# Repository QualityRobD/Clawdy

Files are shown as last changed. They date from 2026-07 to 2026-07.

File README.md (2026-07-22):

# Clawdy: The Anthropic Status Monitor

Clawdy is a dedicated desktop hardware monitor that tracks the operational status of Claude's infrastructure (claude.ai, Console, API, and Code). Using two I2C OLED displays as expressive "eyes," the system provides immediate, ambient visual feedback on service degradation, API outages, and network connectivity.

## Features
* **Real-Time API Polling:** Tracks `status.claude.com` for active outages and reflects the system health natively.
* **Expressive State Machine:** Features over a dozen eye animations (winks, lazy eyes, matrix rain) during normal operation, and distinct visual alert states (Angry Eyes, X Eyes) when infrastructure degrades or a schema mismatch occurs.
* **Resilient Polling:** Built with a reliability-first mindset, gracefully handling network timeouts, HTTP errors, and JSON payload changes without hard-crashing. 
* **Dynamic WiFi Provisioning:** Uses `WiFiManager` to spin up a captive portal (`Clawdy_Setup`) on first boot, keeping local network credentials entirely out of the source code.
* **Hardware Factory Reset:** Built-in startup trap allows for easy network clearing.

## 📶 Wi-Fi Setup & User Manual

Clawdy handles network credentials securely by keeping them off the codebase and storing them directly in local memory.
* The XIAO ESP32-C5 microcontroller supports dual-band Wi-Fi 6 (2.4 GHz and 5 GHz), allowing Clawdy to connect to most modern networks without compatibility issues.
* The Wi-Fi manager allows access to standard networks where a name and password are required. (Enterprise networks requiring a username/VPN are not currently supported).

### Initial Setup (First Boot)
1. **Power On:** Plug Clawdy in. You will see the "CLAWDY" splash screen for 3 seconds.
2. **Access Point Mode:** Because no networks are saved, the screens will read `"CONNECTING TO: WIFI"`. Clawdy will broadcast its own temporary Wi-Fi network.
3. **Connect:** Use your phone or computer to connect to the Wi-Fi network named **`Clawdy_Setup`**.
4. **Configure:** A captive portal should automatically pop up. (If it doesn't, open a web browser and navigate to `192.168.4.1`). Click "Configure WiFi", select your local network, and enter your password.
5. **Success:** Clawdy will save the credentials to its flash memory, automatically restart, and perform a "Happy" eye trick once connected to the internet.

### Setup Timeout 
For security and stability, the configuration portal will only stay active for **3 minutes (180 seconds)**. 
* If you do not enter credentials within that window, Clawdy will display `"SETUP TIMEOUT / REBOOTING..."` and restart itself to try again.

### How to Reset / Wipe Wi-Fi Credentials
If you move Clawdy to a new location or change your router password, you'll need to wipe the old network from memory:
1. Power cycle (unplug and replug) the device.
2. Immediately after the "CLAWDY" splash screen finishes, a 3-second trap window will appear reading `"HOLD 'BOOT' TO WIPE WIFI"`.
3. Press and hold your BOOT button (wired to GPIO 28) during this window.
4. The screens will switch to `"WIPING..."`. 
5. The device will completely erase the old credentials and reboot back into the initial `Clawdy_Setup` Access Point mode so you can connect it to the new network.

## Bill of Materials (BOM)

**Electronics & Circuitry**
* 1x Seeed Studio XIAO ESP32-C5 development board with soldered pins
* 2x 0.96 Inch OLED Display Module 128x64 SSD1306 (I2C)
* 1x Breadboard
* 24 AWG solid core hook wire kit (6 colors)
* 1x Power Battery
* 1x Carry case

**Soldering Equipment**
* Pinecil soldering iron
* 65W Anker Nano USB-C power adapter and high-power USB-C cable
* AUSTOR 60-40 Tin Lead Rosin Core Solder Wire
* Desoldering wick and soldering flux paste
* Soldering desk pad

**3D Printing & Enclosure**
* Terracotta Matte PLA filament

**Post-Processing & Finishing**
* Wet sandpaper (180, 300, 600, 1000, 1500, and 2000 grit)
* Micro-Mesh SoftTouch Pads (1500- 12000)
* Tamiya Polishing Compount Fine
* Tamiya Polishing Compount Finish
* Renaissance Micro-Crystalline Wax Polish (uncessary, but adds extra sheen and protection)
* High-quality microfiber towels
* High-quality wood polishing microfiber buffing pads

## 3D Printed Enclosure
* The repository includes a large edition Claw-D mascot chassis featuring a direct rear USB-C cable pass-through.
* The chassis features a precision screen retention slot designed to fit standard 0.96-inch PCBs.
* The base of the design utilizes a stable eight leg squid structure.
* The chassis OpenSCAD file supports multiple isolated print modes, allowing you to independently print the base, cap, legs, and arms.
* The independent arms mode automatically generates the pieces laid flat for vertical pin printing.
* The repository includes a separate internal electronics sled.
* The sled features specific left and right OLED pockets to securely seat the displays.
* The sled incorporates an ESP32 cradle base with dedicated underside clearance for USB ports and buttons.
* The sled utilizes 0.5mm friction tolerance rails on the outside to easily adjust the fit.
  * *Note on tolerances:* The 0.5mm friction rails and 0.4mm global clearances were designed and tested on a Bambu Lab P2S. If you are using an older or less precise printer, you may need to apply slight negative horizontal expansion in your slicer.

## Software Dependencies
* [Adafruit GFX Library](https://github.com/adafruit/Adafruit-GFX-Library)
* [Adafruit SSD1306](https://github.com/adafruit/Adafruit_SSD1306)
* [WiFiManager](https://github.com/tzapu/WiFiManager)
* **ArduinoJson (IMPORTANT: Must use Version 6.x)** 
  *(Note: This codebase utilizes `DynamicJsonDocument`, which was deprecated in ArduinoJson v7).*

## Architecture Notes
* `program_sketch.ino`: The main operational loop and rendering pipeline.
* `anthropic_status.h`: The networking thread, managing HTTP/TLS connections and JSON payload deserialization.
* `eye_tricks.h`: The geometry and animation library for the OLED eyes.

## License
MIT License

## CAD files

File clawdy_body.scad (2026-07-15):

// =========================================================================
// CLAW-D MASCOT: LARGE EDITION (SLED READY, REAR SCREW MOUNTS)
// =========================================================================

/* [Fixed Hardware Specifications] */
pcb_w = 27.3;         // Physical width of standard 0.96" PCB
glass_t = 2.4;        // Front of glass to back of PCB
clearance = 0.4;      // 3D printing tolerance fit
$fn = 24;             // Curve smoothness

/* [Adjustable Features] */
print_mode = "arms";  // [ "assembled", "base", "cap", "legs", "arms" ]
eye_w = 25;           // Width of the front eye cutouts - original: 23
eye_h = 12;           // Height of the front eye cutouts - original: 14
eye_mm_height_adjust = 5;
eye_chamfer = 2.0;    // How much the outer edges slant outward for better viewing angle
top_softness = 1.0;   // How much the outer top edge is chamfered (leaves the rest flat for supports)

usb_hole_height_adjuster = 5.0;

// Variables to protect the internal cavity while adding pin holes
bottom_thickness_added = 2.4; 
pin_height = 3.0;
hole_depth = 3.6; 

clawd_chassis();

module clawd_chassis() {
    
    // 1. HARDCODED LARGE PARAMETERS
    unit = 7.2;
    head_w = 86.4;    // 12 * 7.2
    head_h = 69.12;   // 86.4 / 1.25
    head_d = 39.6;    // 5.5 * 7.2

    if (print_mode == "base" || print_mode == "cap" || print_mode == "assembled") {
        difference() {
            // 2. THE ACCURATE PROPORTIONAL OUTER SHELL
            union() {
                // Main Head (Bottom extended downward by bottom_thickness_added)
                translate([-head_w/2, -head_d/2, 2*unit - bottom_thickness_added]) 
                    cube([head_w, head_d, head_h + bottom_thickness_added]);
                
                if (print_mode == "assembled") {
                    // Left Side Stub/Arm
                    translate([-head_w/2 - 2*unit, -unit/2, head_h/2 + unit]) 
                        cube([2*unit, unit, 2*unit]);
                    
                    // Right Side Stub/Arm
                    translate([head_w/2, -unit/2, head_h/2 + unit]) 
                        cube([2*unit, unit, 2*unit]);
                        
                    // ---- STABLE EIGHT LEG SQUID STRUCTURE ----
                    for(x = [-4.5*unit, -2.5*unit, 1.5*unit, 3.5*unit]) {
                        for(y = [-head_d/2, head_d/2 - unit]) {
                            // Legs end where the newly lowered chassis begins
                            translate([x, y, 0]) cube([unit, unit, 2*unit - bottom_thickness_added]);
                        }
                    }
                }
            }
            
            // 3. INTERNAL CAVITY (Untouched coordinates)
            translate([-4.5*unit, -head_d/2 + 2.5, 2*unit + 2])
                cube([9*unit, head_d - 5, head_h - 3.8]);
                
            // 4. FRONT FACE EYE WINDOWS (Two-Stage Cut for Supports + Soft Edge)
            translate([-2.5*unit - eye_w/2.75, -head_d/2 - 0.1, head_h - 2.25*unit - eye_h/2 + eye_mm_height_adjust])
                chamfered_eye(is_left = true);
                
            translate([2.5*unit - eye_w/1.5, -head_d/2 - 0.1, head_h - 2.25*unit - eye_h/2 + eye_mm_height_adjust])
                chamfered_eye(is_left = false);
                
            // 5. PRECISION SCREEN RETENTION SLOT (Untouched coordinates)
            translate([-4.5*unit, -head_d/2 + 2.5, 2*unit + 2])
                cube([9*unit, glass_t + clearance, head_h - 3.8]);

            // 6. UPPER WIRING & PIN RELIEF CHANNEL (Untouched coordinates)
            translate([-4.5*unit, -head_d/2 + 2.5, head_h + unit - 2])
                cube([9*unit, head_d - 5, 3]);
                
            // 7. DIRECT REAR USB-C CABLE PASS-THROUGH (Untouched coordinates)
            translate([-8, head_d/2 - 4, 2*unit + usb_hole_height_adjuster])
                cube([16, 10, 10]);

            // 8. LEG ALIGNMENT HOLES
            if (print_mode == "base") {
                for(x = [-4.5*unit, -2.5*unit, 1.5*unit, 3.5*unit]) {
                    for(y = [-head_d/2, head_d/2 - unit]) {
                        // Cut upwards from the newly lowered chassis bottom
                        translate([x + 1.2 - clearance/2, y + 1.2 - clearance/2, 2*unit - bottom_thickness_added - 0.1])
                            cube([unit - 2.4 + clearance, unit - 2.4 + clearance, hole_depth + 0.1]);
                    }
                }
            }
            
            // 8.5 ARM ALIGNMENT HOLES
            if (print_mode == "base") {
                // Left Arm Hole
                translate([-head_w/2 - 0.1, -unit/2 + 1.2 - clearance/2, head_h/2 + unit + 1.2 - clearance/2])
                    cube([hole_depth + 0.1, unit - 2.4 + clearance, 2*unit - 2.4 + clearance]);
                    
                // Right Arm Hole
                translate([head_w/2 - hole_depth, -unit/2 + 1.2 - clearance/2, head_h/2 + unit + 1.2 - clearance/2])
                    cube([hole_depth + 0.1, unit - 2.4 + clearance, 2*unit - 2.4 + clearance]);
            }
                
            // 9. TUPPERWARE SPLIT CUTTERS
            if (print_mode == "base") {
                difference() {
                    translate([-head_w/2 - 5, -head_d/2 - 5, 2*unit + head_h - 4]) 
                        cube([head_w + 10, head_d + 10, 20]);
                    translate([-head_w/2 + 2, -head_d/2 + 2, 2*unit + head_h - 4]) 
                        cube([head_w - 4, head_d - 4, 2]);
                }
            }
            
            if (print_mode == "cap") {
                translate([-100, -100, -20]) 
                    cube([200, 200, 2*unit + head_h - 4 + 20]);
                    
                translate([-head_w/2 + 1.8, -head_d/2 + 1.8, 2*unit + head_h - 4 - 0.1]) 
                    cube([head_w - 3.6, head_d - 3.6, 2.2]);
            }
        }
    }

    // 10. INDEPENDENT LEGS MODE
    if (print_mode == "legs") {
        for(x = [-4.5*unit, -2.5*unit, 1.5*unit, 3.5*unit]) {
            for(y = [-head_d/2, head_d/2 - unit]) {
                union() {
                    // Leg base (exactly meets the lowered bottom of the chassis)
                    translate([x, y, 0]) 
                        cube([unit, unit, 2*unit - bottom_thickness_added]);
                    // Alignment pin
                    translate([x + 1.2, y + 1.2, 2*unit - bottom_thickness_added]) 
                        cube([unit - 2.4, unit - 2.4, pin_height]);
                }
            }
        }
    }
    
    // 11. INDEPENDENT ARMS MODE (Laid flat for vertical pin printing)
    if (print_mode == "arms") {
        // Generates two identical arms side-by-side on the Z=0 plane
        for(x = [-1.5*unit, 1.5*unit]) {
            translate([x - unit, -unit/2, 0]) {
                union() {
                    // Arm body (laying on its flat side)
                    cube([2*unit, unit, 2*unit]);
                    // Alignment pin (pointing straight up)
                    translate([1.2, 1.2, 2*unit]) 
                        cube([2*unit - 2.4, unit - 2.4, pin_height]);
                }
            }
        }
    }
}
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

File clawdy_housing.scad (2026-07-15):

// ==========================================
// CLAW-D MASCOT: INTERNAL ELECTRONICS SLED
// ==========================================

oled_w = 27.8; // old: 27.8
oled_h = 28.6; // old: 28.0 & 28.02

esp_l = 26.5; // esp cradel wall length
esp_w = 17.85; // esp cradel wall space distance (old: 18mm)
esp_h = 12.0; // esp cradel wall height
esp_z_lift = 6.0; // Raises the board to create component clearance underneath
esp_y_offset = 0; // Negative = closer to the front wall, Positive = further back

sled_width = 63.0;  

// --- ASYMMETRICAL ADJUSTMENT ---
// Front restored to original position (-16.5)
// Back extended by exactly 1mm from original (16.5 -> 17.5)
front_y = -16.5; 
back_y = 17.5;   
sled_depth = back_y - front_y; // Dynamically calculates to 34.0mm

sled_height = 65.0; 
wall_thick = 2.0;
front_wall_thick = 4.0; // RESTORED to 4.0 for OLED clearance
eye_z_offset = 25.12; // eyehole vertical position

render_sled();

module render_sled() {
    difference() {
        union() {
            // Main U-Shape Sled
            difference() {
                translate([-sled_width/2, front_y, 0])
                    cube([sled_width, sled_depth, sled_height]);
                
                translate([-(sled_width - wall_thick*2)/2, front_y + front_wall_thick, wall_thick])
                    cube([sled_width - wall_thick*2, sled_depth, sled_height]);
            }
            
            // ESP32 Cradle Base (Extended to front wall, raised by 2mm)
            translate([-(esp_w + 2)/2, front_y + front_wall_thick, wall_thick])
                cube([esp_w + 2, back_y - (front_y + front_wall_thick), esp_h + esp_z_lift]);

            // ESP32 Cradle shelf (Raised by 2mm)
            translate([-(esp_w + 2)/2, front_y + front_wall_thick, wall_thick + 12 + esp_z_lift])
                cube([esp_w + 2, ((back_y - esp_l + esp_y_offset) - (front_y + front_wall_thick)) + 14.5, 2]);
                
    
            // 0.5mm Friction Tolerance Rails (outside of sled to easily adjust length)
            translate([-sled_width/2 - 0.7, front_y, 0])
                cube([0.7, sled_depth, sled_height]);
            translate([sled_width/2, front_y, 0])
                cube([0.7, sled_depth, sled_height]);
        }
        
        // --- SUBTRACTIONS ---
        
        // ESP32 Drop-In Seat 
        // Lifted by esp_z_lift so the board rests on a 2mm ledge
        translate([-esp_w/2, back_y - esp_l + esp_y_offset, wall_thick + esp_z_lift + 0.1])
            cube([esp_w, esp_l + 1, esp_h]);

        // ESP32 Underside Component Clearance (USB & Buttons)
        // 10mm wide gap leaves ~3.9mm ledges on both sides for the board to sit on.
        depth = back_y - 16 + esp_y_offset;
        translate([-10/2, depth, 3])
            cube([10, 16.1, esp_z_lift + 0.2]);

        // Left OLED Pocket
        translate([-sled_width/2 + wall_thick + 0.5, front_y - 0.1, eye_z_offset])
            cube([oled_w, front_wall_thick + 1, oled_h]);
            
        // Right OLED Pocket
        translate([sled_width/2 - wall_thick - 0.5 - oled_w, front_y - 0.1, eye_z_offset])
            cube([oled_w, front_wall_thick + 1, oled_h]);
    }
}

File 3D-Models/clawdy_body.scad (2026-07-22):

// =========================================================================
// CLAW-D MASCOT: LARGE EDITION (SLED READY, REAR SCREW MOUNTS)
// =========================================================================

/* [Fixed Hardware Specifications] */
pcb_w     = 27.3;             // Physical width of standard 0.96" OLED PCB
glass_t   = 2.4;              // Depth from front of OLED glass to back of PCB
clearance = 0.4;              // Global 3D printing tolerance fit
$fn       = 24;               // Curve smoothness (resolution for cylinders/arcs)

/* [Adjustable Features] */
print_mode           = "base"; // [ "assembled", "base", "cap", "legs", "arms" ]
eye_w                = 25;     // Width of the front eye cutouts (original: 23)
eye_h                = 12;     // Height of the front eye cutouts (original: 14)
eye_mm_height_adjust = 5;      // Vertical shift for the eye cutouts
eye_chamfer          = 2.0;    // Outward slant on outer edges for better viewing angle
top_softness         = 1.0;    // Top edge chamfer amount (leaves the rest flat for supports)
leg_inset            = 3.0;    // Inward adjustment distance for front and back legs

usb_hole_height_adjuster = 5.0; // Vertical shift for the rear USB-C cable pass-through

// Variables to protect the internal cavity while adding alignment pin holes
bottom_thickness_added = 2.4;  // Extra thickness added to the base for structural integrity
pin_height             = 3.0;  // Height of the alignment pins (arms/legs)
hole_depth             = 3.6;  // Depth of the receiving holes (allows 0.6mm clearance for glue/fit)

/* [Base Pocket Adjustments] */
pocket_w_extra = clearance + 0.2; // Extra width for base pocket (default was global clearance: 0.4)
pocket_d_extra = clearance + 0.2; // Extra depth for base pocket (default was global clearance: 0.4)
pocket_h_extra = clearance + 0.0; // Extra height/depth for base pocket (default was hardcoded 0.1)

/* [Magnetic Clasp & Split] */
magnet_dia      = 5.2; // Diameter of hidden pocket (+0.2mm tolerance for 5mm magnet)
magnet_depth    = 3.2; // Depth of hidden pocket (+0.2mm tolerance for 3mm magnet)
cover_thickness = 0.6; // Layers of plastic hiding the magnet (0.6 = 3x 0.2mm print layers)

/* [Sled Button Alignment] */
button_hole_d              = 2.0;  // Hole size for boot/reset access (sized for a paperclip)
esp_w                      = 18.2; // Matches internal sled's ESP width for exact offset mapping
left_button_hole_x_offset  = 4.25; // X-axis offset for the left (BOOT) button
right_button_hole_x_offset = 5.0;  // X-axis offset for the right (RESET) button
button_hole_y              = -5;   // Y-axis depth alignment (Maps to sled's updated math: 17.5 - 22.25)

// =========================================================================
// MAIN EXECUTION
// =========================================================================

if (print_mode == "cap") {
    // Flips the cap 180 degrees and drops the flat seam exactly to the Z=0 build plate
    // Math: Z-height shift = (2 * unit + head_h - 4)
    translate([0, 0, 2*7.2 + 69.12 - 4]) 
        rotate([180, 0, 0]) 
            clawd_chassis();
} else {
    clawd_chassis();
}

// =========================================================================
// CHASSIS MODULE
// =========================================================================

module clawd_chassis() {
    
    // 1. HARDCODED LARGE PARAMETERS
    unit   = 7.2;
    head_w = 86.4;    // 12 * 7.2 (Total head width)
    head_h = 69.12;   // 86.4 / 1.25 (Total head height proportional to width)
    head_d = 39.6;    // 5.5 * 7.2 (Total head depth)
    
    // Split line and Boss parameters for two-part printing
    split_z = 2*unit + head_h - 4; // Z-height where the cap splits from the base
    boss_w  = 6.0;                 // Width of the alignment bosses
    boss_d  = 12.0;                // Depth of the alignment bosses
    boss_h  = 3.0;                 // Height of the alignment bosses
    boss_x  = 37.8;                // X-axis position (centered precisely in the solid side-walls)

    // Render the main body if we are printing the base, cap, or full assembly
    if (print_mode == "base" || print_mode == "cap" || print_mode == "assembled") {
        difference() {
            // 2. THE ACCURATE PROPORTIONAL OUTER SHELL
            union() {
                // Main Head (Bottom extended downward by bottom_thickness_added)
                translate([-head_w/2, -head_d/2, 2*unit - bottom_thickness_added]) 
                    cube([head_w, head_d, head_h + bottom_thickness_added]);
                    
                // Structural Alignment Bosses (Added to Cap for reassembly)
                if (print_mode == "cap" || print_mode == "assembled") {
                    translate([boss_x - boss_w/2, -boss_d/2, split_z - boss_h])
                        cube([boss_w, boss_d, boss_h]);
                    translate([-boss_x - boss_w/2, -boss_d/2, split_z - boss_h])
                        cube([boss_w, boss_d, boss_h]);
                }
                
                // Attach non-removable limbs for 'assembled' visualization
                if (print_mode == "assembled") {
                    // Left Side Stub/Arm
                    translate([-head_w/2 - 2*unit, -unit/2, head_h/2 + unit]) 
                        cube([2*unit, unit, 2*unit]);
                    
                    // Right Side Stub/Arm
                    translate([head_w/2, -unit/2, head_h/2 + unit]) 
                        cube([2*unit, unit, 2*unit]);
                        
                    // ---- STABLE EIGHT LEG SQUID STRUCTURE ----
                    for(x = [-4.5*unit, -2.5*unit, 1.5*unit, 3.5*unit]) {
                        for(y = [-head_d/2 + leg_inset, head_d/2 - unit - leg_inset]) {
                            // Legs end where the newly lowered chassis begins
                            translate([x, y, 0]) 
                                cube([unit, unit, 2*unit - bottom_thickness_added]);
                        }
                    }
                }
            }
            
            // 3. INTERNAL CAVITY (Untouched coordinates)
            // Hollows out the center for the PCB sled and wiring
            translate([-4.5*unit, -head_d/2 + 2.5, 2*unit + 2])
                cube([9*unit, head_d - 5, head_h - 3.8]);
                
            // 4. FRONT FACE EYE WINDOWS (Two-Stage Cut for Supports + Soft Edge)
            eye_shift_x = 0.4; // Fine-tuning offset to perfectly center the eyes
            
            // Left Eye Cutout
            translate([-2.5*unit - eye_w/2.75 + eye_shift_x, -head_d/2 - 0.1, head_h - 2.25*unit - eye_h/2 + eye_mm_height_adjust])
                chamfered_eye(is_left = true);
                
            // Right Eye Cutout
            translate([2.5*unit - eye_w/1.5 + eye_shift_x, -head_d/2 - 0.1, head_h - 2.25*unit - eye_h/2 + eye_mm_height_adjust])
                chamfered_eye(is_left = false);
                
            // 5. PRECISION SCREEN RETENTION SLOT (Untouched coordinates)
            // Secures the OLED glass directly against the front wall
            translate([-4.5*unit, -head_d/2 + 2.5, 2*unit + 2])
                cube([9*unit, glass_t + clearance, head_h - 3.8]);

            // 6. UPPER WIRING & PIN RELIEF CHANNEL (Untouched coordinates)
            // Provides headroom for dupont wires or headers at the top of the sled
            translate([-4.5*unit, -head_d/2 + 2.5, head_h + unit - 2])
                cube([9*unit, head_d - 5, 3]);
                
            // 7. DIRECT REAR USB-C CABLE PASS-THROUGH (Untouched coordinates)
            translate([-8, head_d/2 - 4, 2*unit + usb_hole_height_adjuster])
                cube([16, 10, 10]);
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

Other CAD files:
3D-Models/clawdy_housing.scad

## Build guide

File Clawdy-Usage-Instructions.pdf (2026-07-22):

# Clawdy: Anthropic Status Monitor

Provisioning & Setup

1. Power: Supply standard USB power.
2. Connect: Join the Clawdy_Setup Wi-Fi from any client.
3. Provision: Pass local Wi-Fi credentials via the captive portal (VPN unsupported)

UI Telemetry

- Blinking Eyes: Systems operational.
- 'X' Eyes: Active outage (degraded service scrolls below).
- Angry Brows: Systemic error (e.g., firewall block, routing timeout).

Hardware Toggles

Ensure the microcontroller is fully pushed back into the device. The two buttons are very small and near the back of the device.

- [R] Pinhole: Reboot device
- [B] Pinhole (Wipe): Tap [R]. At the startup prompt, hold [B] for 2 seconds to wipe network config.
- Do this to change wifi settings if you want to connect Clawdy to a new network

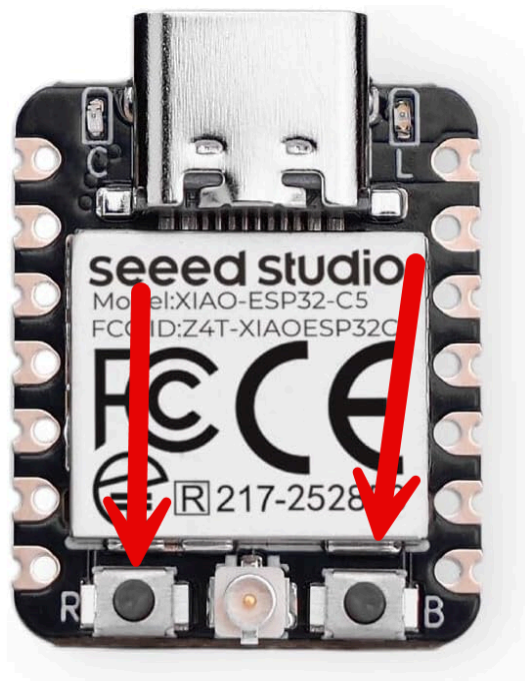
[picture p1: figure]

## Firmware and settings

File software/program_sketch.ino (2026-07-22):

// =========================================================================
// CLAWDY MASCOT: MAIN EXECUTION SCRIPT
// Hardware: ESP32 (Optimized for XIAO ESP32-C5) & Dual 0.96" I2C OLEDs
// =========================================================================

#include <SPI.h>
#include <Wire.h>
#include <Adafruit_GFX.h>
#include <Adafruit_SSD1306.h>
#include <WiFiManager.h>
#include <esp_wifi.h>

// LINK SEPARATE TAB LOGIC: Pulls in the network engine compiled in your other sub-files
// These files inject external variables like 'clawdExpressionState' and 'downTargetText'
#include "anthropic_status.h" 
#include "eye_tricks.h"

// --- OLED HARDWARE DEFINITIONS ---
#define SCREEN_WIDTH         128 
#define SCREEN_HEIGHT        64 
#define OLED_RESET           -1 
#define SCREEN_ADDRESS_LEFT  0x3D // Jumpered/Resistor-modified OLED address
#define SCREEN_ADDRESS_RIGHT 0x3C // Default OLED address

// --- ESP32 CHIP-SPECIFIC BOOT BUTTON PIN MAPPING ---
#if CONFIG_IDF_TARGET_ESP32C5
  #define BOOT_BUTTON 28 // XIAO ESP32-C5 boot pin
#elif CONFIG_IDF_TARGET_ESP32C3 || CONFIG_IDF_TARGET_ESP32C6
  #define BOOT_BUTTON 9  // Standard C3/C6 boot pin
#else
  #define BOOT_BUTTON 0  // Classic ESP32, S2, and S3 boot pin
#endif

// Instantiate the dual display objects sharing the same I2C bus
Adafruit_SSD1306 leftEye(SCREEN_WIDTH, SCREEN_HEIGHT, &Wire, OLED_RESET);
Adafruit_SSD1306 rightEye(SCREEN_WIDTH, SCREEN_HEIGHT, &Wire, OLED_RESET);

// --- GLOBAL STATE VARIABLES ---
// Exposed to sub-tabs via 'extern' in their respective header files
bool clawdOperational    = true; 
bool eyesOpen            = true; 
int  lastExpressionState = 0; // Tracks previous state to detect recovery events

unsigned long nextTandemBlink = 0; 
unsigned long nextStatusCheck = 0;

const int           blinkDuration   = 150;   // Milliseconds the eyes stay closed during a blink
const unsigned long apiPollInterval = 60000; // Frequency of checking the Anthropic status API

// =========================================================================
// SYSTEM INITIALIZATION
// =========================================================================

void setup() {
  delay(500); // Startup rail power buffer to allow hardware to stabilize
  Serial.begin(115200);
  
  // Initialize I2C specifically mapped to the XIAO ESP32-C5 pins
  Wire.begin(D4, D5); 

  // Initialize both OLED "eyes" on the shared I2C bus
  if(!leftEye.begin(SSD1306_SWITCHCAPVCC, SCREEN_ADDRESS_LEFT)) {
    Serial.println(F("Left eye allocation failed"));
  }
  if(!rightEye.begin(SSD1306_SWITCHCAPVCC, SCREEN_ADDRESS_RIGHT)) {
    Serial.println(F("Right eye allocation failed"));
  }

  // === STAGE 1: BOOT SPLASH SCREEN ===
  leftEye.clearDisplay(); rightEye.clearDisplay();
  leftEye.setTextSize(3); rightEye.setTextSize(3); // Large, bold text
  leftEye.setTextColor(SSD1306_WHITE); rightEye.setTextColor(SSD1306_WHITE);

  // Center "CLAWDY" text (Width: 108px. Offset: X=10, Y=20)
  leftEye.setCursor(10, 20); leftEye.print("CLAWDY");
  rightEye.setCursor(10, 20); rightEye.print("CLAWDY");
  leftEye.display(); rightEye.display();

  delay(3000); // Hold splash screen for 3 seconds


  // === FACTORY RESET TRAP (THE STARTUP WINDOW) ===
  // Allows users to clear saved WiFi credentials if moving the device
  pinMode(BOOT_BUTTON, INPUT_PULLUP); 
  
  // 1. Display the 3-second warning window
  leftEye.clearDisplay(); rightEye.clearDisplay();
  leftEye.setTextSize(1); rightEye.setTextSize(1);
  leftEye.setCursor(15, 20); leftEye.print("HOLD 'BOOT'");
  rightEye.setCursor(15, 20); rightEye.print("HOLD 'BOOT'");
  leftEye.setCursor(15, 35); leftEye.print("TO WIPE WIFI");
  rightEye.setCursor(15, 35); rightEye.print("TO WIPE WIFI");
  leftEye.display(); rightEye.display();

  // 2. Scan the button rapidly for 3 seconds (30 loops of 100ms)
  bool wipeTriggered = false;
  for (int i = 0; i < 30; i++) {
    if (digitalRead(BOOT_BUTTON) == LOW) {
      wipeTriggered = true;
      break; // Button pressed, break out of the timer early to immediately execute wipe
    }
    delay(100);
  }

  // 3. Execute the wipe if triggered
  if (wipeTriggered) {
    WiFiManager wm;
    leftEye.clearDisplay(); rightEye.clearDisplay();
    leftEye.setCursor(20, 30); leftEye.print("WIPING...");
    rightEye.setCursor(20, 30); rightEye.print("WIPING...");
    leftEye.display(); rightEye.display();
    
    wm.resetSettings(); // Nuke the saved WiFi memory
    
    delay(3000); // Give the user time to read confirmation
    ESP.restart(); // Reboot into the AP Setup portal
  }

  // === STAGE 2: NETWORK HANDSHAKE SCREEN ===
  leftEye.clearDisplay(); rightEye.clearDisplay();

  // Line 1: "CONNECTING TO:" (Size 1. Width: 84px. Offset: X=22)
  leftEye.setTextSize(1); rightEye.setTextSize(1);
  leftEye.setCursor(22, 20); leftEye.print("CONNECTING TO:");
  rightEye.setCursor(22, 20); rightEye.print("CONNECTING TO:");
  
  // Line 2: "WIFI" (Size 2. Width: 48px. Offset: X=40)
  leftEye.setTextSize(2); rightEye.setTextSize(2);
  leftEye.setCursor(40, 35); leftEye.print("WIFI");
  rightEye.setCursor(40, 35); rightEye.print("WIFI");
  
  leftEye.display(); rightEye.display();

  // ===  Force MAC address change - only needed if firewalls block microcontrollers or odd MAC addresses
  // 1. Wake up the Wi-Fi interface in Client (Station) mode
  // WiFi.mode(WIFI_STA); 
  
  // 2. Clone the mobile phone's identity
  // uint8_t spoofedMAC[] = {<MAC_ADDRESS>}; 
  //esp_wifi_set_mac(WIFI_IF_STA, &spoofedMAC[0]);

  // Force Google/Cloudflare DNS 
  // (Passing zeros ensures the router still handles standard IP assignment via DHCP)
  IPAddress primaryDNS(8, 8, 8, 8); 
  IPAddress secondaryDNS(1, 1, 1, 1);
  WiFi.config(IPAddress(0,0,0,0), IPAddress(0,0,0,0), IPAddress(0,0,0,0), primaryDNS, secondaryDNS);

  // === START WIFI MANAGER ===
  WiFiManager wm;
  wm.setDebugOutput(false);
  wm.setConfigPortalTimeout(180); // 3-minute timeout for the captive portal

  if (!wm.autoConnect("Clawdy_Setup")) {
    Serial.println("Portal configuration timeout. Resetting...");
    leftEye.clearDisplay(); rightEye.clearDisplay();
    leftEye.setCursor(15, 30); leftEye.print("SETUP TIMEOUT");
    rightEye.setCursor(15, 30); rightEye.print("REBOOTING...");
    leftEye.display(); rightEye.display();
    delay(3000); // Give them 3 seconds to read it
    ESP.restart();
  }

  // Play a happy animation once connected (function provided by eye_tricks.h)
  executeTrick_Happy(3000);

  Serial.println("Network handshake secured successfully!");
  
  // Initialize random behaviors
  randomSeed(analogRead(0));
  nextTandemBlink = millis() + random(5000, 7000); // Stable 5-7 second tandem blink horizon
  nextTrickTime   = millis() + random(trickIntervalMin, trickIntervalMax); // Set the first happy trick time slot
  
  // Perform the initial API request immediately
  nextStatusCheck = millis() + checkAnthropicStatus();
}

// =========================================================================
// MAIN PROCESSING LOOP
// =========================================================================

void loop() {
  unsigned long currentTime = millis();

  // --- OUTAGE RECOVERY CELEBRATION ---
  // If we were previously in an error state (>0) and are now operational (0)
  if (lastExpressionState != 0 && clawdExpressionState == 0) {
    executeTrick_Happy(); // Smile because the servers are back!
  }
  lastExpressionState = clawdExpressionState; // Update the tracking record

  // --- API ROUTING NETWORK THREAD ---
  if (currentTime >= nextStatusCheck) {
    nextStatusCheck = millis() + checkAnthropicStatus();
  }

  // --- RENDERING ROUTINES ---
  leftEye.clearDisplay();
  rightEye.clearDisplay();

  // Re-stamp the static hardware assembly identifiers (default text settings)
  leftEye.setTextSize(1); rightEye.setTextSize(1);
  leftEye.setTextColor(SSD1306_WHITE); rightEye.setTextColor(SSD1306_WHITE);

  // --- RENDERING PIPELINE EXPRESSION SWITCH ---
  // clawdExpressionState is updated globally by checkAnthropicStatus()
  
  if (clawdExpressionState == 0) {
    
    // === STATE 0: NORMAL OPERATIONAL LOOP (SYNCHRONIZED TANDEM BLINK) ===
    
    // Check if it's time to interrupt the idle state with an animation trick
    if (currentTime >= nextTrickTime) {
      runRandomEyeTrick();
      nextTrickTime = currentTime + random(trickIntervalMin, trickIntervalMax); // Reset interval
    }
    
    // Handle the standard idle blinking logic
    if (currentTime >= nextTandemBlink) {
      eyesOpen = false;
      // Hold the blink shut until blinkDuration passes
      if (currentTime >= nextTandemBlink + blinkDuration) {
        eyesOpen = true;
        nextTandemBlink = currentTime + random(5000, 7000); // Schedule next blink
      }
    }

    // Draw the eyes (Open = Large squares, Closed = Flat lines)
    if (eyesOpen) {
      leftEye.fillRect( 44, 12, 40, 40, SSD1306_WHITE);
      rightEye.fillRect(44, 12, 40, 40, SSD1306_WHITE);
    } else {
      leftEye.fillRect( 44, 30, 40, 6, SSD1306_WHITE);
      rightEye.fillRect(44, 30, 40, 6, SSD1306_WHITE);
    }

  } 
  else if (clawdExpressionState == 1) {
    
    // === STATE 1: VALID CLAUDE OUTAGE (CRISPY GEOMETRIC X SHAPES) ===
    
    // Left Eye 'X' (Drawn with multiple offset lines for thickness)
    leftEye.drawLine(44, 12, 84, 52, SSD1306_WHITE);
    leftEye.drawLine(44, 13, 83, 52, SSD1306_WHITE);
    leftEye.drawLine(45, 12, 84, 51, SSD1306_WHITE);
    leftEye.drawLine(84, 12, 44, 52, SSD1306_WHITE);
    leftEye.drawLine(84, 13, 45, 52, SSD1306_WHITE);
    leftEye.drawLine(83, 12, 44, 51, SSD1306_WHITE);

    // Right Eye 'X' (Drawn with multiple offset lines for thickness)
    rightEye.drawLine(44, 12, 84, 52, SSD1306_WHITE);
    rightEye.drawLine(44, 13, 83, 52, SSD1306_WHITE);
    rightEye.drawLine(45, 12, 84, 51, SSD1306_WHITE);
    rightEye.drawLine(84, 12, 44, 52, SSD1306_WHITE);
    rightEye.drawLine(84, 13, 45, 52, SSD1306_WHITE);
    rightEye.drawLine(83, 12, 44, 51, SSD1306_WHITE);

    // Dynamic text floor centering for the specific component that is down
    // (Text size 1 characters are 6px wide with spacing)
    int leftStartPos = (SCREEN_WIDTH - (downTargetText.length() * 6)) / 2;
    if (leftStartPos < 0) leftStartPos = 0; 
    leftEye.setCursor(leftStartPos, 53);  leftEye.print(downTargetText);
    rightEye.setCursor(leftStartPos, 53); rightEye.print(downTargetText);
    
  } 
  else if (clawdExpressionState == 2) {
    
    // === STATE 2: SYSTEMIC ERROR / SCHEMA MISMATCH (ANGRY BROW Slices) ===
    
    // Left Angry Eye (Square with a black triangle subtracted from the top)
    leftEye.fillRect(44, 12, 40, 40, SSD1306_WHITE);
    leftEye.fillTriangle(44, 12, 84, 12, 84, 42, SSD1306_BLACK);

    // Right Angry Eye (Square with a black triangle subtracted from the top)
    rightEye.fillRect(44, 12, 40, 40, SSD1306_WHITE);
    rightEye.fillTriangle(44, 12, 84, 12, 44, 42, SSD1306_BLACK);

    // Dynamic text floor centering for Systemic alerts
    int leftStartPos = (SCREEN_WIDTH - (downTargetText.length() * 6)) / 2;
    if (leftStartPos < 0) leftStartPos = 0; 
    leftEye.setCursor(leftStartPos, 53);  leftEye.print(downTargetText);
    rightEye.setCursor(leftStartPos, 53); rightEye.print(downTargetText);
  }

  // Push buffer to the physical screens
  leftEye.display();
  rightEye.display();
  
  delay(10); // Short breather to prevent watchdog resets and screen tearing
}

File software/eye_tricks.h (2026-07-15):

#ifndef EYE_TRICKS_H
#define EYE_TRICKS_H

#include <Adafruit_SSD1306.h>

// Expose display objects from the primary sketch tab
extern Adafruit_SSD1306 leftEye;
extern Adafruit_SSD1306 rightEye;

// Track when the next random trick can fire (every 30 to 45 seconds)
unsigned long nextTrickTime = 0;
const unsigned long trickIntervalMin = 35000;
const unsigned long trickIntervalMax = 65000;

// --- TRICK 1: THE CASUAL WINK ---
void executeTrick_Wink() {
  // Left eye drops to a line, right eye stays wide open
  leftEye.clearDisplay();
  leftEye.fillRect(44, 30, 40, 6, SSD1306_WHITE);
  leftEye.display();
  
  delay(400); // Hold the wink briefly
}

// --- TRICK 2: THE HAPPY COMPANION (LOOK UP CURVES) ---
void executeTrick_Happy(int holdTime = 1500) {
  // Replace squares with happy up-curved arches
  leftEye.clearDisplay(); rightEye.clearDisplay();
  
  // Draw thick happy arc geometries using overlapping circles and black masks
  leftEye.fillCircle(64, 40, 20, SSD1306_WHITE);
  leftEye.fillCircle(64, 44, 20, SSD1306_BLACK);
  rightEye.fillCircle(64, 40, 20, SSD1306_WHITE);
  rightEye.fillCircle(64, 44, 20, SSD1306_BLACK);
  
  leftEye.display(); rightEye.display();
  delay(holdTime); // Hold happy smile expression
}

// --- TRICK 3: DILATION / FOCUS SHIFT ---
void executeTrick_Focus() {
  // Shrink the big block eyes inward to look intensely focused
  for(int i = 0; i < 3; i++) {
    leftEye.clearDisplay(); rightEye.clearDisplay();
    
    // Tightened focused center squares
    leftEye.fillRect(52, 20, 24, 24, SSD1306_WHITE);
    rightEye.fillRect(52, 20, 24, 24, SSD1306_WHITE);
    leftEye.display(); rightEye.display();
    delay(200);
    
    // Flash back out to wide
    leftEye.fillRect(44, 12, 40, 40, SSD1306_WHITE);
    rightEye.fillRect(44, 12, 40, 40, SSD1306_WHITE);
    leftEye.display(); rightEye.display();
    delay(200);
  }
}

// --- TRICK 4: THE MATRIX CODE RAIN ---
void executeTrick_Matrix() {
  // Simulates quick digital data vertical streaming drop arrays
  for (int i = 0; i < 15; i++) {
    leftEye.clearDisplay(); rightEye.clearDisplay();

    // Randomize vertical line segments dropping down across the eye bounding boxes
    int yOffset = (i * 8) % 40;
    leftEye.fillRect(44 + 8, 12 + yOffset, 4, 12, SSD1306_WHITE);
    leftEye.fillRect(44 + 24, 12 + ((yOffset + 16) % 40), 4, 8, SSD1306_WHITE);
    
    rightEye.fillRect(44 + 8, 12 + yOffset, 4, 12, SSD1306_WHITE);
    rightEye.fillRect(44 + 24, 12 + ((yOffset + 16) % 40), 4, 8, SSD1306_WHITE);

    leftEye.display(); rightEye.display();
    delay(100);
  }
}

// --- TRICK 5: THE GLITCH / CYBER TWITCH ---
void executeTrick_Glitch() {
  // A rapid tracking hardware glitch effect where the eyes temporarily shift off-axis
  for (int i = 0; i < 6; i++) {
    leftEye.clearDisplay(); rightEye.clearDisplay();
    
    // Left eye jitters up-left, Right eye jitters down-right
    leftEye.fillRect(44 - 6, 12 - 4, 40, 40, SSD1306_WHITE);
    rightEye.fillRect(44 + 6, 12 + 4, 40, 40, SSD1306_WHITE);
    leftEye.display(); rightEye.display();
    delay(60);

    // Flash back inverted positions
    leftEye.clearDisplay(); rightEye.clearDisplay();
    leftEye.fillRect(44 + 4, 12 + 2, 40, 40, SSD1306_WHITE);
    rightEye.fillRect(44 - 4, 12 - 2, 40, 40, SSD1306_WHITE);
    leftEye.display(); rightEye.display();
    delay(60);
  }
}

// --- TRICK 6: SUSPICIOUS SQUINT / SIDE-EYE ---
void executeTrick_Squint() {
  // Clawd targets his attention left, then right, like an untrusting security daemon
  for (int side = 0; side < 2; side++) {
    leftEye.clearDisplay(); rightEye.clearDisplay();

    // Eyelids compress vertically into thin tracking lenses (12px high)
    // Pupil offsets simulate tracking direction
    int pupilXOffset = (side == 0) ? -12 : 12; 
    
    leftEye.fillRect(44 + pupilXOffset, 26, 40, 12, SSD1306_WHITE);
    rightEye.fillRect(44 + pupilXOffset, 26, 40, 12, SSD1306_WHITE);
    
    leftEye.display(); rightEye.display();
    delay(1000); // Hold the suspicious glare
  }
}

// --- TRICK 7: SUPER CROSS-EYED SQUEEZE (SMOOTH SCALE & IN-AND-DOWN TRANSITION) ---
void executeTrick_Crosseyed() {
  // We execute a 5-step loop to interpolate scale, inward pull, and downward dip simultaneously
  for (int step = 0; step <= 4; step++) {
    leftEye.clearDisplay(); rightEye.clearDisplay();

    // 1. DYNAMICALLY SCALE SIZES: Linearly shrink from 40px down to 20px (50% target)
    int currentSize = 40 - (step * 5); 

    // 2. INTERPOLATE COORDINATE TRAJECTORIES
    int xOffset = step * 6; // Horizontal inward velocity multiplier
    int yOffset = step * 4; // Vertical downward velocity multiplier

    // Left Eye: Pupil shifts RIGHT (44 + xOffset) and DOWN (12 + yOffset)
    leftEye.fillRect(44 + xOffset, 12 + yOffset, currentSize, currentSize, SSD1306_WHITE);

    // Right Eye: Pupil shifts LEFT (44 - xOffset) and DOWN (12 + yOffset)
    // To keep it centered relative to its shrinking box, we balance the anchor coordinate math
    int rightXAnchor = 44 - xOffset + (step * 5); 
    rightEye.fillRect(rightXAnchor, 12 + yOffset, currentSize, currentSize, SSD1306_WHITE);

    leftEye.display(); rightEye.display();
    delay(60); // Frame duration pace (roughly 16 FPS for an organic, readable mechanical transition)
  }
  
  delay(1400); // Hold that intense, tiny cross-eyed expression at the finish line

  // Smoothly snap back out to wide center blocks
  for (int step = 4; step >= 0; step--) {
    leftEye.clearDisplay(); rightEye.clearDisplay();

    int currentSize = 40 - (step * 5);
    int xOffset = step * 6;
    int yOffset = step * 4;

    leftEye.fillRect(44 + xOffset, 12 + yOffset, currentSize, currentSize, SSD1306_WHITE);
    int rightXAnchor = 44 - xOffset + (step * 5);
    rightEye.fillRect(rightXAnchor, 12 + yOffset, currentSize, currentSize, SSD1306_WHITE);

    leftEye.display(); rightEye.display();
    delay(40); // Snaps back slightly faster than the entry compression for a springy look
  }
}
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

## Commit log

2026-07-22 clawdy_body.scad - documentation updates
    [clawdy_body.scad]
2026-07-22 clawdy_housing.scad - update documentation
    [clawdy_housing.scad]
